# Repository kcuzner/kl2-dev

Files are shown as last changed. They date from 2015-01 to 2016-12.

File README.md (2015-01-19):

# Kinetis KL2 Development Board
### Kevin Cuzner

## Objective

Create a development board for a bare-metal ARM Microcontroller with minimal
parts while allowing for maximum prototypability.

## Purpose

To learn from hard experience what exactly is needed to implement from the
ground up a platform using an ARM-based microcontroller

## Idea

The board will have the following:

 * The Freescale MKL26Z32VFM4 48Mhz ARM Cortex-M0+ microcontroller, 32QFN (5mm)
 * Any needed support componenets
 * A DIP-compatible footprint. The goal is to be near the size of a teensy.

The goals are as follows:

 * $10 price point
    * $2.72 for the uC
    * $5 board
    * $3 supporting components
        * Perhaps a USB port even
 * Easy to construct with sufficient SMD soldering skill
 * We will produce 3 of them
    * 1 practice, 2 assembled on camera

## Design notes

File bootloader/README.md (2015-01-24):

# KL26 Bootloader
## Kevin Cuzner

This bootloader operates by checking for an external pin being held high. If
the pin is high, the main bootlaoder method is run. Alternately, the user
program can also directly call the main bootloader method.

The main bootloader method is assigned to live at 0x410, right after the
flash config. The reset handler follows immediately.

Upon reset, the handler invokes startup after disabling the WDT (maybe we
should just leave it on) and setting up the IVT. The startup code does the
appropriate .bss and .data clear/copy and then calls main.

In main, the GPIOs are initialized and the processor checks to see if the
specified GPIO reads high. If it does not, it sets the IVT to point to the
user main startup point (right after the 4K boundary) and jumps to the address
pointed to by the next value (the reset handler in the user program). We may
just simply initiate a reset since I think that would work (testing will be
needed).

If the GPIO is high, the bootloader will proceed to initialize the PLL for
USB operation. After initialization, the bootloader will initialize the USB
driver which should make the device show up on the host machine.

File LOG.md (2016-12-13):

# Kinetis KL2 Development Board
### Kevin Cuzner

This log is meant to help me remember the process I had to go through so that
in the future I can optimize it without forgetting any steps.
    
## Parts So Far

MKL26Z32VFM4-ND IC MCU ARM 32KB FLASH 32QFN $2.72
609-4616-1-ND CONN USB MICRO B RECPT SMT R/A $0.46

## Monologue

### 10/22/2014

I started out wanting to use the teensy 3.1 in bare metal because I was
interested in getting to truely know the ARM architecture. I found that I didn't
understand it well enough to really get in to it, so I began looking around to
see how ARM development is done. I knew only that JTAG could be used to program
a chip.

I discovered (via edaboard question and lots of google) that the M-series of
arm cores have the SWD (serial wire debug) interface which is better for
flashing an initial bootloader. I then located a bootloader tutorial (see
bookmarks) and it struck me that I could accomplish the goal of programming
a bare-metal arm controller. I would use another microcontroller (perhaps an
AVR operating the V-usb library) as a bridge to the SWD and I would write a
program that would load a hex file and program it to the uC via the USB->SWD
bridge.

I then searched for the cheapest ARM controller I could find that has USB
because I wanted to make a USB bootloader. I located the MKL26Z32VFM4 and was
further encouraged to use it when I saw it was of the Kinetis series (the same
that the teensy uses) and so I feel more comfortable that I could work with it.

The family fact datasheet states that the KL2x series is compatible with the
K20 series of Kinetis MCUs. I have placed all relevant datasheets I could find
in the ref folder so that I don't lose them.

I was distracted with the clock setup because I was thinking about what crystal
to purchase. Upon reset, the device is using an internal reference clock
(referred to as FEI (FLL Engaged Internal) mode). Page 456 gives an example of
moving from FEI to PEE (PLL Engaged External) via the state diagram given in
Fig 24-14. From this exercise I learned that I need to choose an external
crystal sufficient to engage the PLL eventually. It is very different to
initialize this chip compared to AVRs (where the clock source is a burned in
fuse) and must happen every time the chip is brought out of reset. Ch 24 talks
about the clock generator, Ch 25 talks about the oscillator specifics.

The specific pins that the osc is connected on appear to be ones denoted by
EXTAL (external clk/osc input). According to the subfamily datasheet, this is
the pin called PTA18 (pin 17 on 32QFN, configured in default/alt0 as EXTAL0. The
XTAL pin is the output. This is PTA19 (pin 18 on 32QFN), configured in default/
alt0 as XTAL0. The crystal is connected across these two pins, with the
(internal?) loading capacitors and possibly a feedback resistor (Rf). The OSC
says that in high-frequency, low-power mode, this resistor is internal. It also
says the loading capacitors can be configured by the OSC0_CR[SCxP] bits.
Capacitances are configured by adding 2, 4, 8, and 16pF to the oscillator load.
In summary: Crystal goes between PTA18 & PTA19, the crystal capacitance is
configured internally when in low-power mode, and the feedback resistor is also
internal. The crystal frequencies supported in this mode are from 3-32Mhz. Using
the internal capacitors is optional, so perhaps it would be best to include pads
for them.

Upon further reading, it seems I must use the high power mode for using the PLL.
Therefore, I will include pads for both the capacitors and the feedback resistor
even though I don't know what values they need to be yet. I asked a stack
exchange question.

The users guide with general tips and tricks says to place a guard ring anchored
at the nearby VSS pin around the crystal and all of the resistors/caps that are
included. We will do this.

### 01/19/2015

The boards have been ordered and are on their way back from the fab. I started
looking more deeply into the software to determine what exactly needs to be
done and over the past couple days I have discovered:

 * The family reference manual. For the future, I need to remember that there
   is a difference between a "datasheet" and "reference manual". The reference
   manual is the several thousand page document that I really want. The
   datasheet is the per-part summary of the electrical and timing
   characteristics.
 * The chip I have chosen and bought (MKL26Z32VFM4) does not have an EzPort and
   will need to be programmed via JTAG or SWD
 * The McHck is very similar to this and uses a bus pirate for programming. I
   will need to purchase a bus pirate.
 * The bus pirate will be very slow for programming this, so I need to write a
   USB bootloader so that it can reprogram itself.

I also managed to locate a header file (FINALLY!!!) inside of a Freescale
Freedom development kit example. I am keeping it in this repo so I don't lose
it. It has been such a hassle to find the software stuff for this...next time
I do this I am going to choose the part, find the REFERENCE MANUAL, find the
headers, and then continue. This could have turned into a waste of money had I
failed to locate any of those.

### 02/02/2015

In order to connect to the device to program the initial bootloader, I have been
reading copious documentation on how exactly to do this thing. The KL26 only
supports the SWD interface, which is fine. I am creating a rudimentary SWD-USB
bridge and some control software so I can issue commands over USB.

A decent reference for the SWD protocol:
http://markdingst.blogspot.com/2014/03/programming-internal-sram-over-swd.html

A good reference is in the ARM SW-DP documentation as well.

The SWD has two main functions: DP (debug port), and AP (access port). The APnDP
bit in any read/write is used to control which one is being accessed. The AP has
a way to select which exact AP is being used via the SELECT register in the DP.
The KL26 provides two AP's: The AHB-AP at SELECT\[31:24\] = 0x00 and the MDM-AP
at SELECT\[31:24\] = 0x01.

 * The AHB-AP is used to actually access the internal memory of the device and
   the documentation is part of the CoreSight documentation which I have added
   to the repo. This seems to be a standard AP.

 * The MDM-AP is the KL26 way to request things such as debug halts, system
   resets, and other things. The documentation for this module is found in
   section 9.3 of the reference manual. This is a nonstandard AP.

Each AP has a number of banks which provide sets of 4 registers used for
interacting with the AP. The bank currently selected is done by some other
bits in the DP SELECT register.

It looks like my quest for programming the device needs to follow steps that
are something like this:

 1. Build an SWD-USB bridge which can execute any SWD command and talk to the
    device. Alternately, buy a programmer.
 2. Write a USB-based bootloader with associated host software that can
    understand intel hex files and compile it with two linker scripts: one that
    locates the program starting at 0x20000000 (inside RAM) and 0x00000000
    (start of flash). The program should know where it lives and prevent writing
    to that location.
 3. Use the SWD to write the RAM version of the bootloader to the internal
    SRAM, set up the IVT to point to 0x20000000, and execute the program from
    that location (set PC to address pointed to by 0x20000004 and run).
 4. With the device running the RAM bootloader, upload the flash bootloader
    using the bootloader host software
 5. Voila! Initial programming complete.

Yesterday, I started hooking up my USB-SWD bridge (built on the Teensy) to the
device. I had two problems:

 1. The device did not respond. I believe my SWD implementation was transmitting
    the JTAG->SWD transition word backwards. It also might have been doing
    reads wrong. However, I'm not even sure if the SWD transition word is needed
    since the device only supports SWD.
 2. When running the system with RESET_b floating, I observed some interesting
    behavior caputured here: http://i.stack.imgur.com/62qti.png. I initially
    thought it was stuck in some sort of boot loop. I read further (not sure
    where) that the watchdog timer might be causing the device to reset. This
    does match with my observed behavior since it starts un-resetting and then
    suddenly drops into reset again. The watchdog timer is enabled by default
    and on the K20 it needed to be turned off or changed within the first 256
    clock cycles to avoid a reset. I need to measure the width of the un-reset
    pulse to make sure, but that could be my problem. The width of the pulse
    didn't change, but the period of the signal varied between 29Khz and 31Khz,
    making for a very jittery image.

### 12/12/2016

Finally some success!! I have managed to finally program one of the KL26 devices
using openocd and the raspberrypi-native interface. Ideally I would have liked
to get the Teensy functioning as an interface, but this seems to work. I suspect
that any low-level openocd interface could be used to program this thing.

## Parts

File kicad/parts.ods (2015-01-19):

Symbol | PN | Description | Cost | Qty | Total | Grand Total
CON1 | 609-4616-1-ND | CONN USB MICRO B RECPT SMT R/A | $0.46 | 1 | $0.46 | $3.67
U1 | MKL26Z32VFM4-ND | IC MCU ARM 32KB FLASH 32QFN | $2.72 | 1 | $2.72
C1, C3 | 490-1532-1-ND | CAP CER 0.1UF 16V 10% X7R 0603 | $0.10 | 2 | $0.20
C2 | 1276-2066-1-ND | CAP CER 4700PF 50V 10% X7R 0603 | $0.10 | 1 | $0.10
C4 | 587-1263-1-ND | CAP CER 2.2UF 16V Y5V 0603 | $0.12 | 1 | $0.12
X1 | 887-2028-ND | CRYSTAL 4MHZ 20PF THRU | $0.33 | 1 | $0.33
R2 | P0.0GCT-ND | RES 0.0 OHM 1/10W JUMP 0603 SMD | $0.10 | 1 | $0.10
R1 | P1.0MGCT-ND | RES 1M OHM 1/10W 5% 0603 SMD | $0.10 | 1 | $0.10
 |  |  |  |  | $0.00
 |  |  |  |  | $0.00
 |  |  |  |  | $0.00
 |  |  |  |  | $0.00
 |  |  |  |  | $0.00
 |  |  |  |  | $0.00
 |  |  |  |  | $0.00
 |  |  |  |  | $0.00
 |  |  |  |  | $0.00
 |  |  |  |  | $0.00
 |  |  |  |  | $0.00
 |  |  |  |  | $0.00
 |  |  |  |  | $0.00
 |  |  |  |  | $0.00
 |  |  |  |  | $0.00
 |  |  |  |  | $0.00
 |  |  |  |  | $0.00
 |  |  |  |  | $0.00
 |  |  |  |  | $0.00

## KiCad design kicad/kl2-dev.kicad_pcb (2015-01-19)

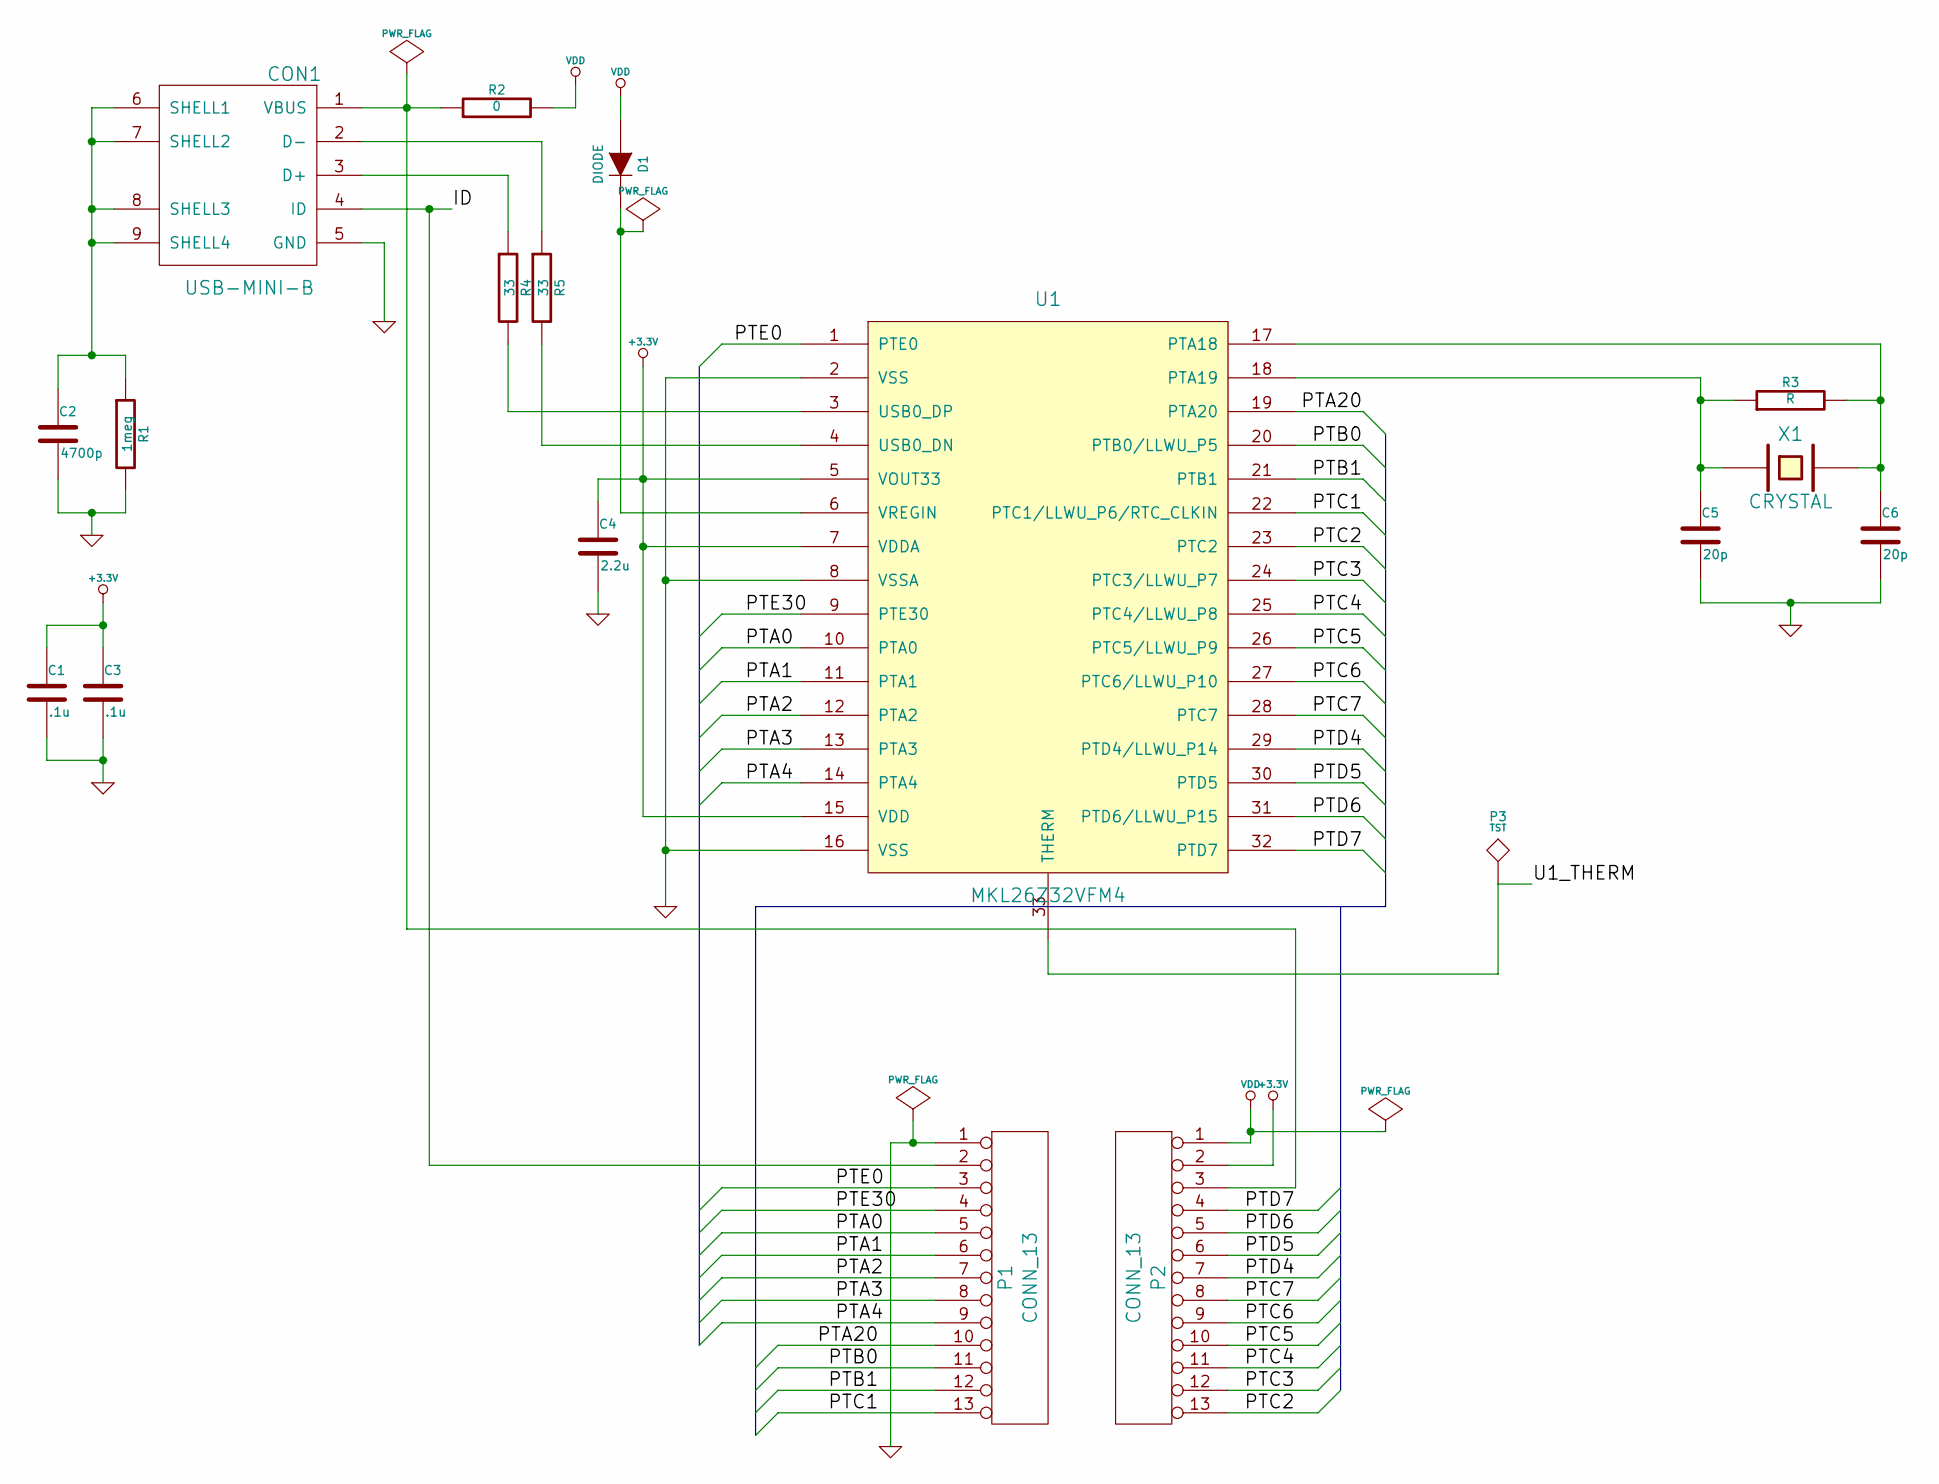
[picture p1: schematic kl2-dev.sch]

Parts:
C1, C3: .1u
C2: 4700p
C4: 2.2u
C5, C6: 20p
CON1: USB-MINI-B
D1: DIODE
P1, P2: CONN_13
P3: TST
R1: 1meg
R2: 0
R3: R
R4, R5: 33
U1: MKL26Z32VFM4
X1: CRYSTAL

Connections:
+3.3V: C1.1, C3.1, C4.1, P2.2, U1.5 (VOUT33), U1.7 (VDDA), U1.15 (VDD)
/ID: CON1.4 (ID), P1.2
/PTA0: P1.5, U1.10 (PTA0)
/PTA1: P1.6, U1.11 (PTA1)
/PTA2: P1.7, U1.12 (PTA2)
/PTA3: P1.8, U1.13 (PTA3)
/PTA4: P1.9, U1.14 (PTA4)
/PTA20: P1.10, U1.19 (PTA20)
/PTB0: P1.11, U1.20 (PTB0/LLWU_P5)
/PTB1: P1.12, U1.21 (PTB1)
/PTC1: P1.13, U1.22 (PTC1/LLWU_P6/RTC_CLKIN)
/PTC2: P2.13, U1.23 (PTC2)
/PTC3: P2.12, U1.24 (PTC3/LLWU_P7)
/PTC4: P2.11, U1.25 (PTC4/LLWU_P8)
/PTC5: P2.10, U1.26 (PTC5/LLWU_P9)
/PTC6: P2.9, U1.27 (PTC6/LLWU_P10)
/PTC7: P2.8, U1.28 (PTC7)
/PTD4: P2.7, U1.29 (PTD4/LLWU_P14)
/PTD5: P2.6, U1.30 (PTD5)
/PTD6: P2.5, U1.31 (PTD6/LLWU_P15)
/PTD7: P2.4, U1.32 (PTD7)
/PTE0: P1.3, U1.1 (PTE0)
/PTE30: P1.4, U1.9 (PTE30)
/U1_THERM: P3.1, U1.33 (THERM)
GND: C1.2, C2.2, C3.2, C4.2, C5.2, C6.2, CON1.5 (GND), P1.1, R1.2, U1.2 (VSS), U1.8 (VSSA), U1.16 (VSS)
unnamed: C5.1, R3.1, U1.18 (PTA19), X1.1
unnamed: C6.1, R3.2, U1.17 (PTA18), X1.2
unnamed: C2.1, CON1.6 (SHELL1), CON1.7 (SHELL2), CON1.8 (SHELL3), CON1.9 (SHELL4), R1.1
unnamed: D1.2 (K), U1.6 (VREGIN)
unnamed: R4.2, U1.3 (USB0_DP)
unnamed: CON1.3 (D+), R4.1
unnamed: R5.2, U1.4 (USB0_DN)
unnamed: CON1.2 (D-), R5.1
unnamed: CON1.1 (VBUS), P2.3, R2.1
VDD: D1.1 (A), P2.1, R2.2

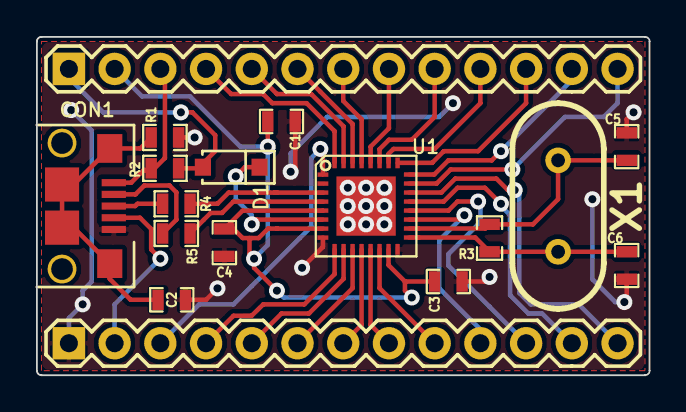
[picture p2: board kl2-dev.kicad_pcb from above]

Board: 2 copper layers, 34.0 x 18.8 mm, 18 parts (1 on the bottom side), 35 nets.

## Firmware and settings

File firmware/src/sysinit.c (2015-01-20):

/*
 * File:        sysinit.c
 * Purpose:     Kinetis L Family Configuration
 *              Initializes processor to a default state
 *
 * Notes:
 *
 *
 */

#include "arm_cm0p.h"
#include "sysinit.h"

/********************************************************************/

/* System clock frequency variables - Represents the current system clock
 * settings
 */
int mcg_clk_hz;
int mcg_clk_khz;
int core_clk_khz;
int periph_clk_khz;
int pll_clk_khz;
int uart0_clk_khz;
uint32 uart0_clk_hz;
extern uint32_t SystemCoreClock;



/********************************************************************/
void sysinit (void)
{
        /* Enable all of the port clocks. These have to be enabled to configure
         * pin muxing options, so most code will need all of these on anyway.
         */
        SIM_SCGC5 |= (SIM_SCGC5_PORTA_MASK
                      | SIM_SCGC5_PORTB_MASK
                      | SIM_SCGC5_PORTC_MASK
                      | SIM_SCGC5_PORTD_MASK
                      | SIM_SCGC5_PORTE_MASK );

        // Release hold with ACKISO:  Only has an effect if recovering from VLLS1, VLLS2, or VLLS3
        // if ACKISO is set you must clear ackiso before calling pll_init
        //    or pll init hangs waiting for OSC to initialize
        // if osc enabled in low power modes - enable it first before ack
        // if I/O needs to be maintained without glitches enable outputs and modules first before ack.
        if (PMC_REGSC &  PMC_REGSC_ACKISO_MASK)
        PMC_REGSC |= PMC_REGSC_ACKISO_MASK;

       /* Ramp up the system clock */
       /* Set the system dividers */
       /* NOTE: The PLL init will not configure the system clock dividers,
        * so they must be configured appropriately before calling the PLL
        * init function to ensure that clocks remain in valid ranges.
        */
        SIM_CLKDIV1 = ( 0
                        | SIM_CLKDIV1_OUTDIV1(OUTDIV1_VAL)
                        | SIM_CLKDIV1_OUTDIV4(OUTDIV4_VAL) );

       /* Initialize PLL */
       /* PLL will be the source for MCG CLKOUT so the core, system, and flash clocks are derived from it */
       mcg_clk_hz = pll_set(CLK0_FREQ_HZ,  /* CLKIN0 frequency */
                             LOW_POWER,     /* Set the oscillator for low power mode */
                             CLK0_TYPE,     /* Crystal or canned oscillator clock input */
                             PLL0_PRDIV,    /* PLL predivider value */
                             PLL0_VDIV,     /* PLL multiplier */
                             MCGOUT);       /* Use the output from this PLL as the MCGOUT */


			/* Check the value returned from pll_init() to make sure there wasn't an error */
       if (mcg_clk_hz < 0x100)
         while(1);

       SIM_SOPT2 |= SIM_SOPT2_PLLFLLSEL_MASK; // set PLLFLLSEL to select the PLL for this clock source

       uart0_clk_khz = ((mcg_clk_hz / 2) / 1000); // UART0 clock frequency will equal half the PLL frequency

       SIM_SOPT2 = ((SIM_SOPT2 & ~SIM_SOPT2_UART0SRC_MASK) | SIM_SOPT2_UART0SRC(1));

	/*
         * Use the value obtained from the pll_init function to define variables
	 * for the core clock in kHz and also the peripheral clock. These
	 * variables can be used by other functions that need awareness of the
	 * system frequency.
	 */
    mcg_clk_khz = mcg_clk_hz / 1000;
    core_clk_khz = mcg_clk_khz / (((SIM_CLKDIV1 & SIM_CLKDIV1_OUTDIV1_MASK) >> 28)+ 1);
    periph_clk_khz = core_clk_khz / (((SIM_CLKDIV1 & SIM_CLKDIV1_OUTDIV4_MASK) >> 16)+ 1);
}

uint32_t pll_set(uint32_t crystal_val, uint8_t hgo_val, uint8_t erefs_val, int8_t prdiv_val, int8_t vdiv_val, uint8_t mcgout_select)
{
    //TODO: Implement the MCG state machine
    return 0x1;
}

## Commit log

2014-10-24 Created initial board with demonstration thermal pad
    We need pin 33 to be on its own special net because it shouldn't be
    connected. We also have not yet routed the flows.
    [kl2-dev.kicad_pcb, kl2-dev.sch]
2014-10-25 Finished routing all but gnd and thermal pad
    [kl2-dev.kicad_pcb, kl2-dev.sch]
2014-10-25 Added thermal pad and vias
    [kl2-dev.kicad_pcb, kl2-dev.sch]
2014-10-25 Fixed thermal pad to behave nicely with vias and finished fill
    [kl2-dev.kicad_pcb]
2014-10-25 Moved labels around to nice places and hid values
    [kl2-dev.kicad_pcb]
2014-10-25 Ignored gerber directory
    [kl2-dev.kicad_pcb]
2014-10-25 Fixed a small mistake in a bus on schematic
    [kl2-dev.sch]
2014-10-25 Fixed oval holes to be large circles
    OSHPark didn't handle them very well
    [kl2-dev.kicad_pcb]
2014-10-25 Reduced thermal via size to minimum drill diameter
    TI has a paper about this and said to keep the via size <0.3mm (we can't quite
    get that small, but we can get close) and to have the spacing of thermal vias
    be about 1mm (we had this already by happenstance)
    [kl2-dev.kicad_pcb]
2014-10-25 Added usb resistors and fixed diode packaging
    [kl2-dev.kicad_pcb, kl2-dev.sch]
2015-01-19 Final schematic and pcb sent to fabricator
    [kl2-dev.kicad_pcb, kl2-dev.sch]
2015-01-19 Finally found a freaking header file
    This was located in the sample code for the Freedom Dev Platform for KL26 MCUs
    http://www.freescale.com/webapp/sps/site/prod_summary.jsp?code=FRDM-KL26Z&fpsp=1&tab=Design_Tools_Tab
2015-01-19 Split readme into log and added parts list spreadsheet
    [parts.ods]
2015-01-19 Added initial build system with linker file
    Yay my first linker file created from a datasheet!
    The basis for this file was found in my teensy-oscilloscope repo:
    https://github.com/kcuzner/teensy-oscilloscope
2015-01-19 Added initial low-level startup code without interrupts
    This is based on the K20 code I have, but with some modifications since the
    Cortex-M0+ processor only supports a subset of the instruction set (I wish the
    compiler would output errors to that effect..instead it just gives back some
    nonsensical error)
2015-01-20 Added interrupt vector table and flash configuration
    Instead of doing the flash configuration with that sequential declaration thing
    that the K20 code had going, we assigned it specifically to live at 0x400. This
    should be much less error prone since screwing that up could possibly brick the
    chip permenently.
2015-01-20 Added initial common ARM Cortex-M0+ header and source
2015-01-20 Began adding shared bootloader region (overlayed)
    The bootloader will operate as a separate program, but with some restrictions:
    * It needs to live in RAM so that the entire flash can be accessed without
    modifying the bootloader code
    * It must be less than 4Kb in size, including variables (usb buffers as well)
    and stack
    The bootloader will basically function as follows:
    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
2015-01-20 Simplified linker script slightly & began adding usb driver for bootloader
2015-01-24 Renamed linker script and moved copy/clear functionality to C
    This is purely for portability. I would prefer to be able to reuse this code
    on a different processor (such as a Cortex-M4) without needing to fix the
    assembly again.
2016-12-13 Made small changes to flash an LED. Success!
